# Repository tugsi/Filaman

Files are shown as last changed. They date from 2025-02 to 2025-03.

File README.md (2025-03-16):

# FilaMan - Filament Management System

[Deutsche Version](README.de.md)

FilaMan is a filament management system for 3D printing. It uses ESP32 hardware for weight measurement and NFC tag management. 
Users can manage filament spools, monitor the status of the Automatic Material System (AMS) and make settings via a web interface. 
The system integrates seamlessly with [Bambu Lab](https://bambulab.com/en-us) 3D printers and [Spoolman](https://github.com/Donkie/Spoolman) filament management.

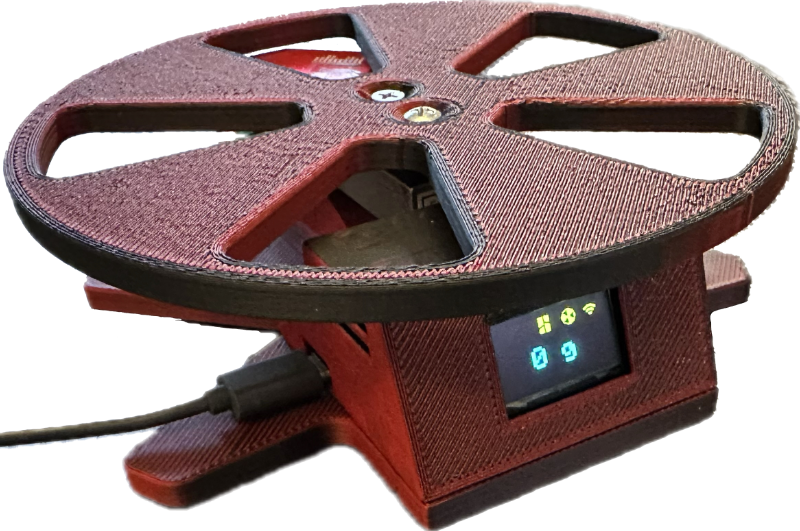
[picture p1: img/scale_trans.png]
Scale


More Images can be found in the [img Folder](/img/)  
or my website: [FilaMan Website](https://www.filaman.app)  
german explanatory video: [Youtube](https://youtu.be/uNDe2wh9SS8?si=b-jYx4I1w62zaOHU)  
Discord Server: [https://discord.gg/my7Gvaxj2v](https://discord.gg/my7Gvaxj2v)

### Now more detailed informations about the usage: [Wiki](https://github.com/ManuelW77/Filaman/wiki)

### ESP32 Hardware Features
- **Weight Measurement:** Using a load cell with HX711 amplifier for precise weight tracking.
- **NFC Tag Reading/Writing:** PN532 module for reading and writing filament data to NFC tags.
- **OLED Display:** Shows current weight, connection status (WiFi, Bambu Lab, Spoolman).
- **WiFi Connectivity:** WiFiManager for easy network configuration.
- **MQTT Integration:** Connects to Bambu Lab printer for AMS control.
- **NFC-Tag NTAG213 NTAG215:** Use NTAG213 (Capacity of 144 bytes), better NTAG215 (Capacity of 540 bytes) because of enaught space on the Tag.

### Web Interface Features
- **Real-time Updates:** WebSocket connection for live data updates.
- **NFC Tag Management:** 
	- Write filament data to NFC tags.
	- so you can use it with automatic Spool detection in AMS
- **Bambulab AMS Integration:** 
  - Display current AMS tray contents.
  - Assign filaments to AMS slots.
  - Support for external spool holder.
- **Spoolman Integration:**
  - List available filament spools.
  - Filter and select filaments.
  - Update spool weights automatically.
  - Track NFC tag assignments.
  - Supports Spoolman Octoprint Plugin.

### If you want to support my work, i would be happy to get a coffe
<a href="https://www.buymeacoffee.com/manuelw" target="_blank">Buy Me A Coffee</a>

## Detailed Functionality

### ESP32 Functionality
- **Control and Monitor Print Jobs:** The ESP32 communicates with the Bambu Lab printer to control and monitor print jobs.
- **Printer Communication:** Uses MQTT for real-time communication with the printer.
- **User Interactions:** The OLED display provides immediate feedback on the system status, including weight measurements and connection status.

### Web Interface Functionality
- **User Interactions:** The web interface allows users to interact with the system, select filaments, write NFC tags, and monitor AMS status.
- **UI Elements:** Includes dropdowns for selecting manufacturers and filaments, buttons for writing NFC tags, and real-time status indicators.

## Hardware Requirements

### Components
- **ESP32 Development Board:** Any ESP32 variant.
[Amazon Link](https://amzn.eu/d/aXThslf)
- **HX711 5kg Load Cell Amplifier:** For weight measurement.
[Amazon Link](https://amzn.eu/d/06A0DLb)
- **OLED 0.96 Zoll I2C white/yellow Display:** 128x64 SSD1306.
[Amazon Link](https://amzn.eu/d/0AuBp2c)
- **PN532 NFC NXP RFID-Modul V3:** For NFC tag operations.
[Amazon Link](https://amzn.eu/d/jfIuQXb)
- **NFC Tags NTAG213 NTAG215:** RFID Tag
[Amazon Link](https://amzn.eu/d/9Z6mXc1)

### Pin Configuration
| Component | ESP32 Pin |
|---|---|
| HX711 DOUT | 16 |
| HX711 SCK | 17 |
| OLED SDA | 21 |
| OLED SCL | 22 |
| PN532 IRQ | 32 |
| PN532 RESET | 33 |
| PN532 SDA | 21 |
| PN532 SCL | 22 |

**Make sure that the DIP switches on the PN532 are set to I2C**

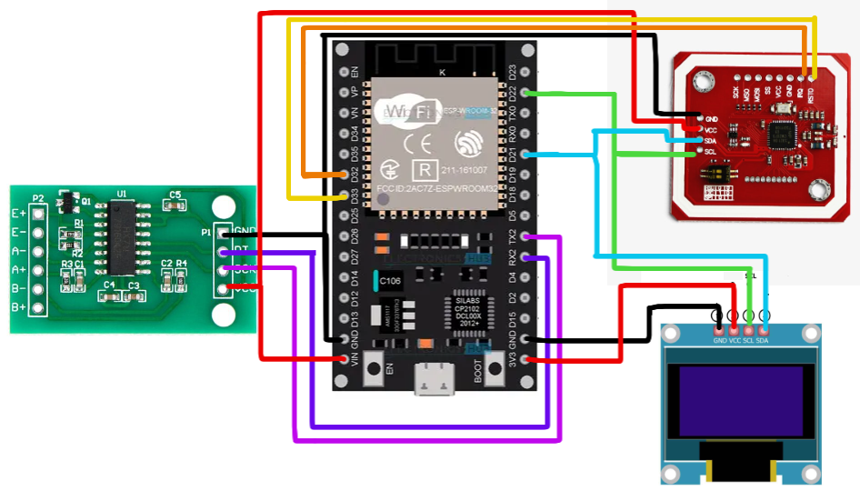
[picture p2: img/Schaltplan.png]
Wiring


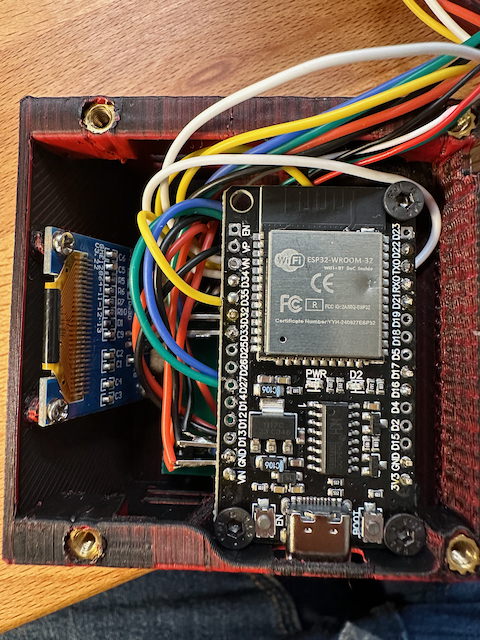
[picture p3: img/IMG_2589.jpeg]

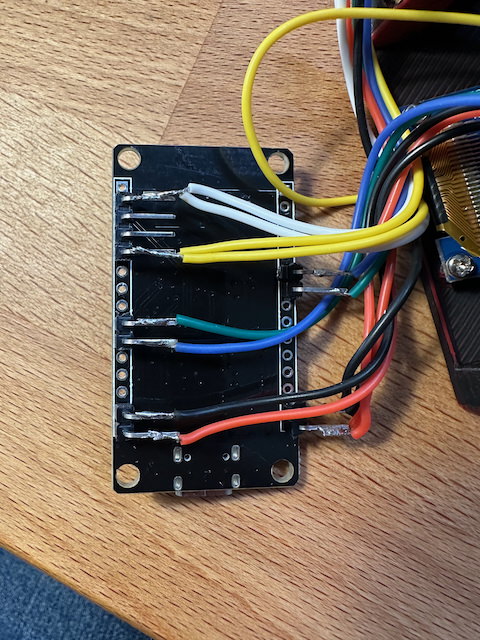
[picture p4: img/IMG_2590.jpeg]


## Software Dependencies

### ESP32 Libraries
- `WiFiManager`: Network configuration
- `ESPAsyncWebServer`: Web server functionality
- `ArduinoJson`: JSON parsing and creation
- `PubSubClient`: MQTT communication
- `Adafruit_PN532`: NFC functionality
- `Adafruit_SSD1306`: OLED display control
- `HX711`: Load cell communication

### Installation

## Prerequisites
- **Software:**
  - [PlatformIO](https://platformio.org/) in VS Code
  - [Spoolman](https://github.com/Donkie/Spoolman) instance
- **Hardware:**
  - ESP32 Development Board
  - HX711 Load Cell Amplifier
  - Load Cell (weight sensor)
  - OLED Display (128x64 SSD1306)
  - PN532 NFC Module
  - Connecting wires

## Important Note
You have to activate Spoolman in debug mode, because you are not able to set CORS Domains in Spoolman yet.

```
# Enable debug mode
# If enabled, the client will accept requests from any host
# This can be useful when developing, but is also a security risk
# Default: FALSE
#SPOOLMAN_DEBUG_MODE=TRUE
```

## Step-by-Step Installation
### Easy Installation (Google Chrome or Microsoft Edge)
1. **Go to [FilaMan Installer](https://www.filaman.app/installer.html)**

2. **Plug you device in and push Connect button**

3. **Select your Device Port and push Intall**

4. **Initial Setup:**
    - Connect to the "FilaMan" WiFi access point.
    - Configure WiFi settings through the captive portal.
    - Access the web interface at `http://filaman.local` or the IP address.

### Compile by yourself
1. **Clone the Repository:**
    ```bash
    git clone https://github.com/ManuelW77/Filaman.git
    cd FilaMan
    ```
2. **Install Dependencies:**
    ```bash
    pio lib install
    ```
3. **Flash the ESP32:**
    ```bash
    pio run --target upload
    ```
4. **Initial Setup:**
    - Connect to the "FilaMan" WiFi access point.
    - Configure WiFi settings through the captive portal.
    - Access the web interface at `http://filaman.local` or the IP address.

## Documentation

### Relevant Links
- [PlatformIO Documentation](https://docs.platformio.org/)
- [Spoolman Documentation](https://github.com/Donkie/Spoolman)
- [Bambu Lab Printer Documentation](https://www.bambulab.com/)

### Tutorials and Examples
- [PlatformIO Getting Started](https://docs.platformio.org/en/latest/tutorials/espressif32/arduino_debugging_unit_testing.html)
- [ESP32 Web Server Tutorial](https://randomnerdtutorials.com/esp32-web-server-arduino-ide/)

## License

This project is licensed under the MIT License. See the [LICENSE](LICENSE) file for details.

## Materials

### Useful Resources
- [ESP32 Official Documentation](https://docs.espressif.com/projects/esp-idf/en/latest/esp32/)
- [Arduino Libraries](https://www.arduino.cc/en/Reference/Libraries)
- [NFC Tag Information](https://learn.adafruit.com/adafruit-pn532-rfid-nfc/overview)

### Community and Support
- [PlatformIO Community](https://community.platformio.org/)
- [Arduino Forum](https://forum.arduino.cc/)
- [ESP32 Forum](https://www.esp32.com/)

## Availability

The code can be tested and the application can be downloaded from the [GitHub repository](https://github.com/ManuelW77/Filaman).

### If you want to support my work, i would be happy to get a coffe
<a href="https://www.buymeacoffee.com/manuelw" target="_blank">Buy Me A Coffee</a>

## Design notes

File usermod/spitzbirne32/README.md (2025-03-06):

## Modifications

To reduce costs, components were sourced from AliExpress instead of Amazon. However, differences in dimensions and mounting hole spacing necessitated adjustments to the 3D-printed parts. Additionally M3 heat inserts were used to limit M4 screws to a minimum.
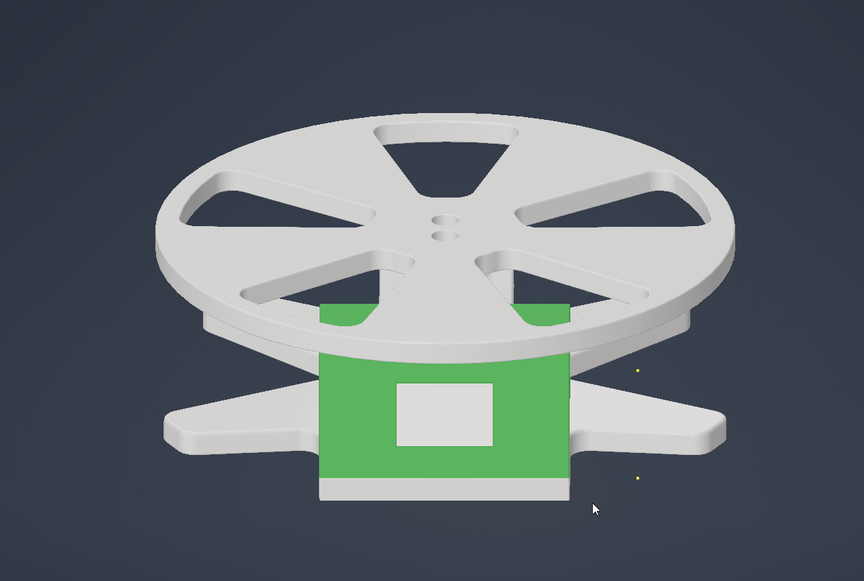
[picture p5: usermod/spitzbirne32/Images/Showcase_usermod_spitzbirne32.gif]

---

List of parts that were used:
- Display: https://aliexpress.com/item/1005007389730469.html
- Scale(5KG with HX711): https://aliexpress.com/item/1005006827930173.html
- NFC Reader: https://aliexpress.com/item/1005005973913526.html
- NFC Chips: https://aliexpress.com/item/1005006332360160.html
- [VORON](https://vorondesign.com/) Heat Inserts M3 OD5mm L4mm: https://aliexpress.com/item/1005003582355741.html  - make sure to select the correct size

---

- **Parts are designed to be printed in ABS/ASA.** Shrinking compensation not needed.

- **Display and Scale Adjustments:** The AliExpress-sourced display and scale had different dimensions and hole spacings compared to the Amazon versions. The 3D models were modified to accommodate these differences, ensuring proper fit and functionality.
   -  measurement of my Display & Scale to check if your parts will fit can be found in the images folder

- **Screw Size and Heat Inserts:** All holes originally designed for M4 screws were resized to fit M3 screws. Standard VORON heat inserts were incorporated to provide durable threading. This change standardizes the hardware and simplifies assembly.

- **Display Mounting:** The display is now mounted using M3 screws with VORON heat inserts. The display's mounting holes need to be drilled to 3mm to accommodate the M3 screws.

- **Scale Top Surface:** The top surface of the scale was modified to allow M3 socket head cap screws to sit flush with the 3D-printed part. This design ensures that the filament spool rests flat without interference.

- **NFC Reader Mounting:** The NFC reader is also secured using M3 screws and VORON heat inserts, maintaining consistency across all components.

- **Scale Base Mounting:** The only M4 screws required are for attaching the metal part of the scale to its base.

## Benefits of Modifications

- **Cost Reduction:** Sourcing components from AliExpress offers a more affordable alternative to Amazon, making the project more accessible.

- **Standardized Hardware:** Using M3 screws and [VORON](https://vorondesign.com/) heat inserts throughout the assembly simplifies the build process and reduces the variety of required hardware.

- **Enhanced Compatibility:** Adjustments to the 3D models ensure compatibility with readily available components, accommodating variations in part dimensions.

## Assembly Instructions

1. **Component Preparation:**
   - Carefully drill the display's mounting holes to 3mm to fit M3 screws.

2. **Heat Insert Installation:**
   - install VORON M3 heat inserts into the designated holes in the 3D-printed housing/case for the ESP32 and Scale top &#8594; [heat insert location pictures](./Images/README.md)

3. **Component Mounting:**
   - Attach the display, scale, and NFC reader to their respective mounts using M3 screws.
   - Secure the metal part of the scale to its base using M4 screws.

4. **Final Assembly:**
   - Assemble all components according to the original FilaMan instructions, ensuring that all modified parts fit correctly and function as intended.

For detailed assembly guides and additional resources, refer to the [original FilaMan documentation](https://github.com/ManuelW77/Filaman).

## Conclusion

These modifications to the FilaMan project provide a cost-effective and standardized approach to building a filament management system. By sourcing components from AliExpress and adjusting the 3D models accordingly, users can achieve the same functionality at a reduced cost, with the added benefit of using uniform hardware throughout the assembly.

## Changelog

### Version 1.0 - 2025-03-04
- Initial release of modifications for AliExpress-sourced components.
- Adjusted 3D models to fit different display and scale dimensions.
- Replaced M4 screws with M3 screws and integrated VORON heat inserts.
- Modified display mounting, requiring drilling to 3mm for M3 screws.
- Adjusted scale top surface for flush screw placement.
- Standardized NFC reader mounting with M3 screws and VORON heat inserts.
- Retained M4 screws only for metal scale attachment.

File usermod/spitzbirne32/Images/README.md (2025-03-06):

## **Heat insert location**

Housing: 
- every hole is made to fit a heat insert
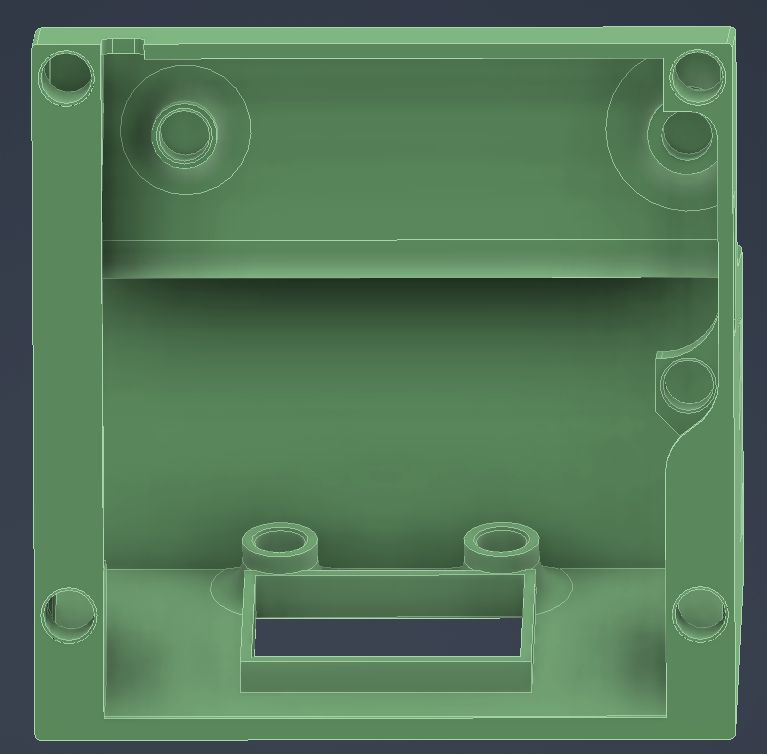
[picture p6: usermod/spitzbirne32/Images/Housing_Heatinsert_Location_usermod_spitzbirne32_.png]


---
Scale top: 
- two heat inserts for the NFC Reader
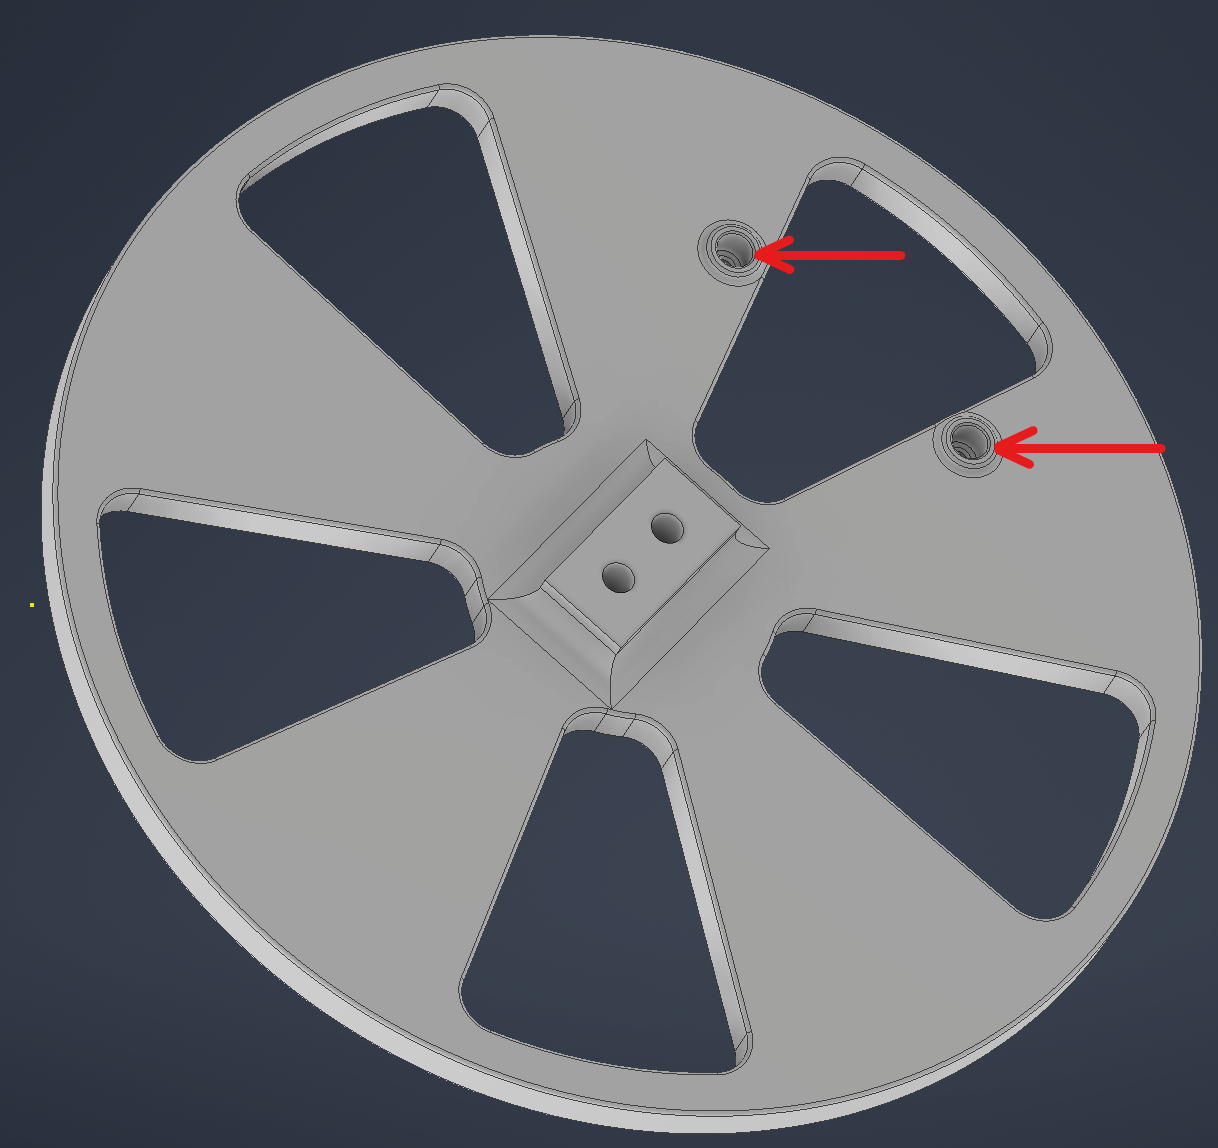
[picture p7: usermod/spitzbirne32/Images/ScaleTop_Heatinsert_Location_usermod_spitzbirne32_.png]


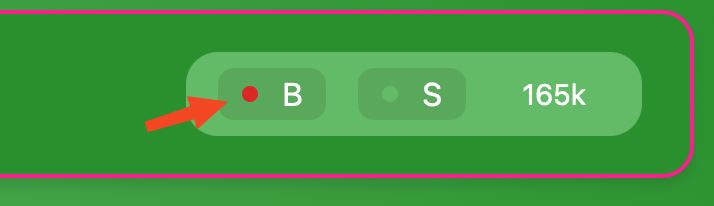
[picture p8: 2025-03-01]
img/7-enable.png

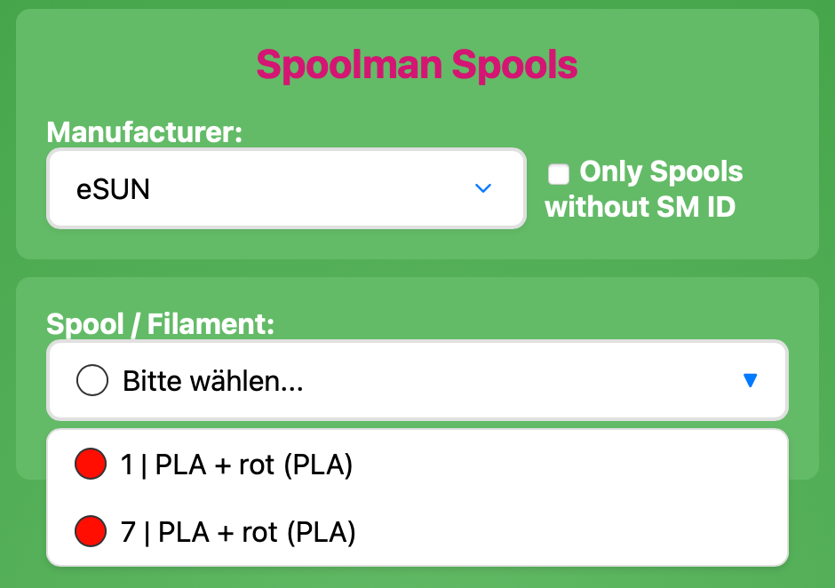
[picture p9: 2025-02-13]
img/web_spoolman.png

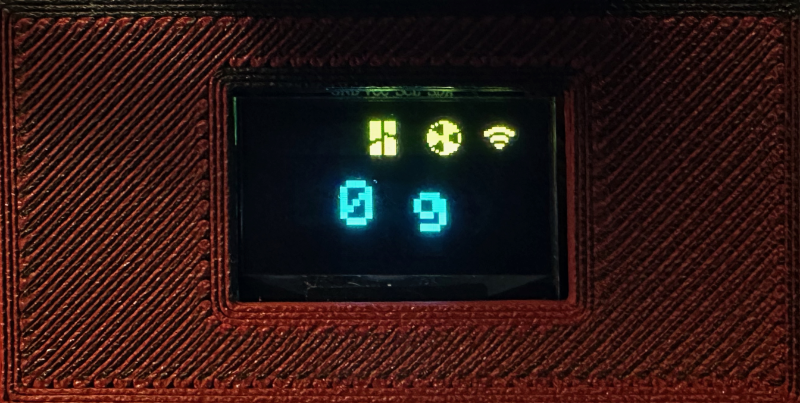
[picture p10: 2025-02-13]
img/display_1.png

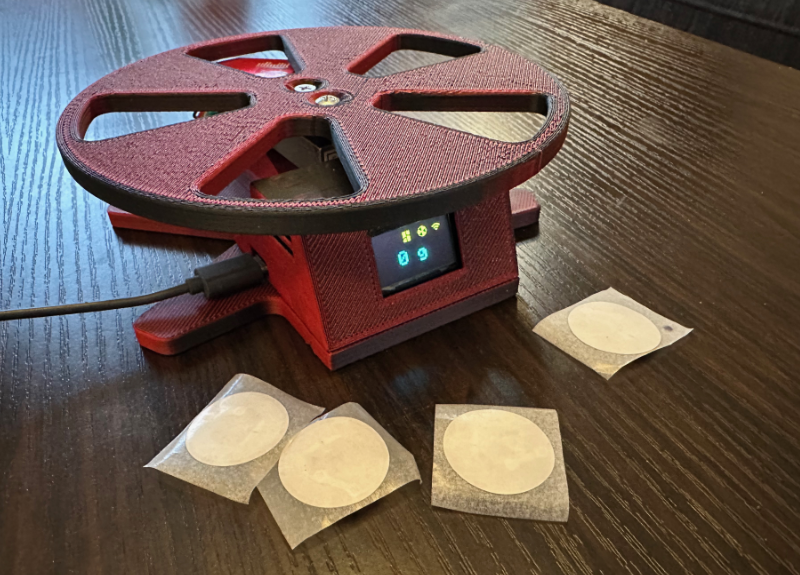
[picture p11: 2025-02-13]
img/scale_1.png

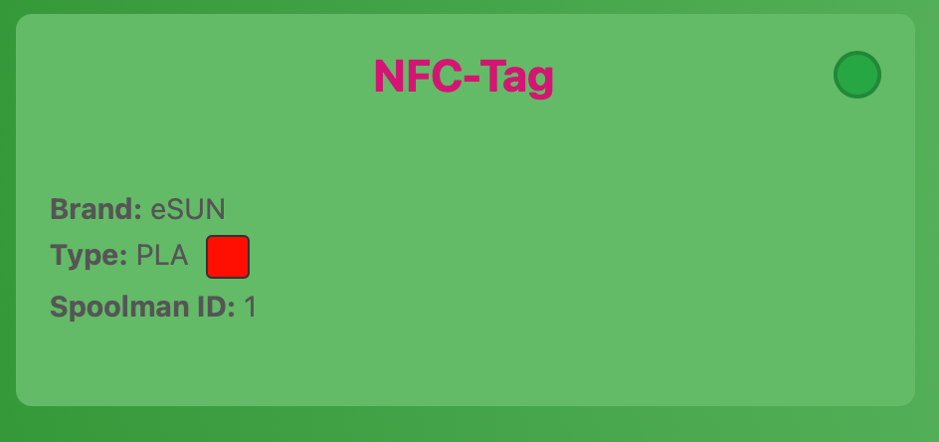
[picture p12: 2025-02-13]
img/web_nfc.png

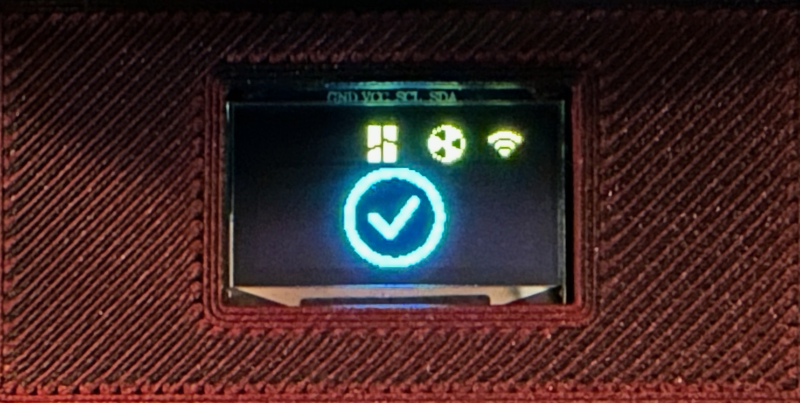
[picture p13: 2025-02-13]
img/display_4.png

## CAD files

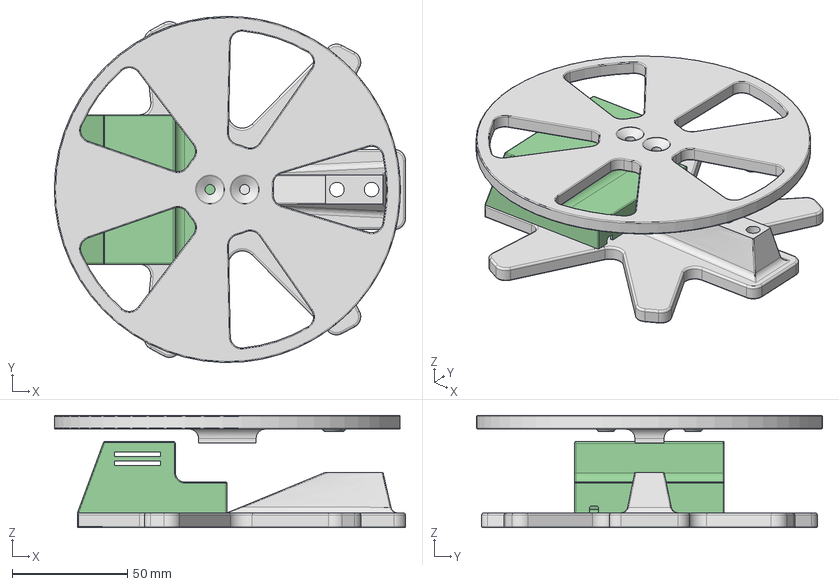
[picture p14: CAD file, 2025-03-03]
_3D Print Files/FilaMan-Waage.step
152.3 x 150.0 x 48.7 mm
Boden
Spulenablage
Deckel

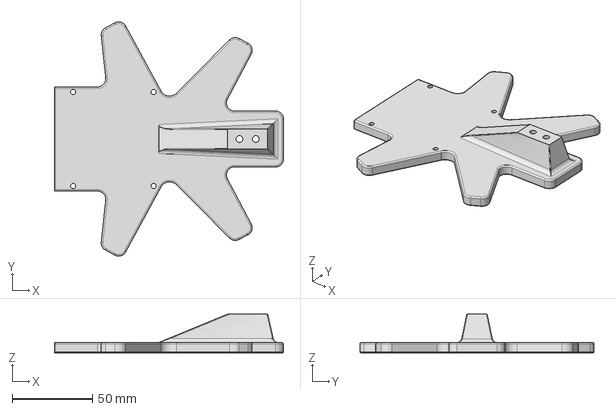
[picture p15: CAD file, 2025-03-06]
usermod/spitzbirne32/CAD/Base_usermod_spitzbirne32.stp
142.3 x 145.6 x 24.0 mm

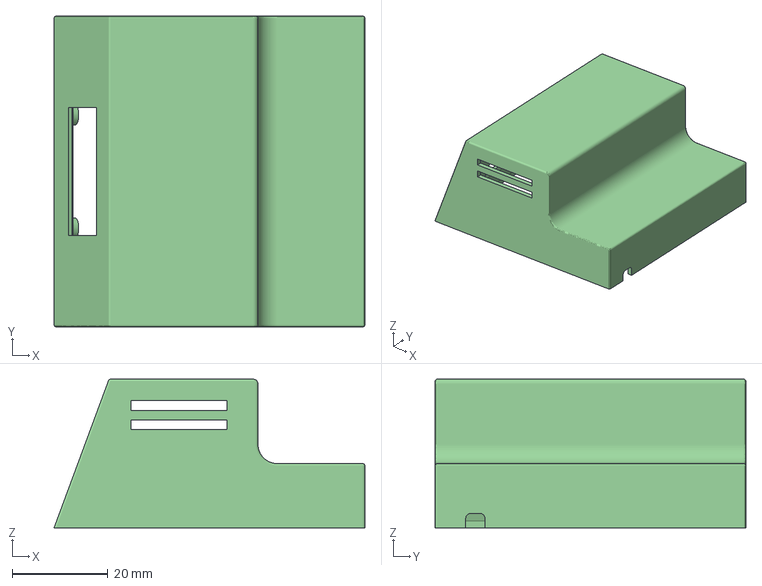
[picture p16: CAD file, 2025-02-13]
_3D Print Files/Housing.3mf
64.8 x 64.8 x 31.0 mm

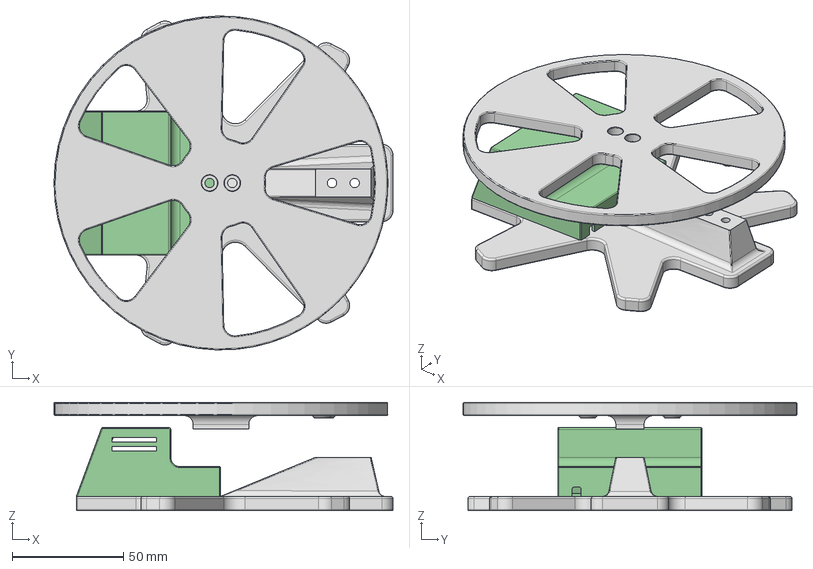
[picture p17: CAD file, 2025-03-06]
usermod/spitzbirne32/CAD/FilaMan-Scale_usermod_spitzbirne32.stp
152.3 x 150.0 x 48.7 mm
Boden
Spulenablage
Deckel

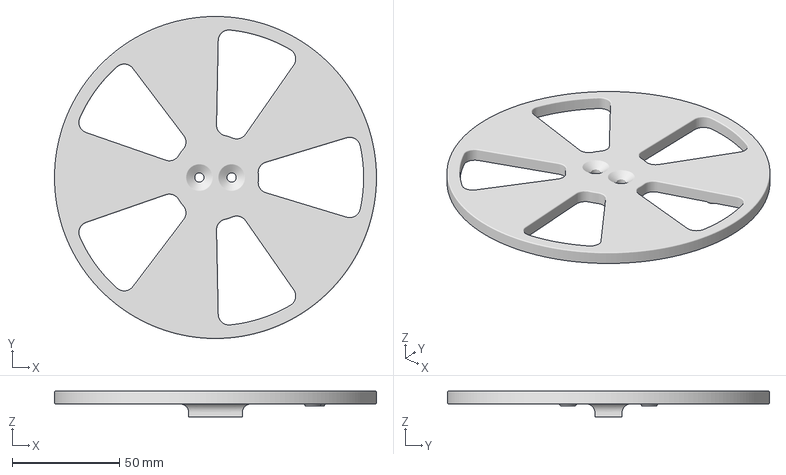
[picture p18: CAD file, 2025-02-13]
_3D Print Files/Table.3mf
150.0 x 150.0 x 12.0 mm

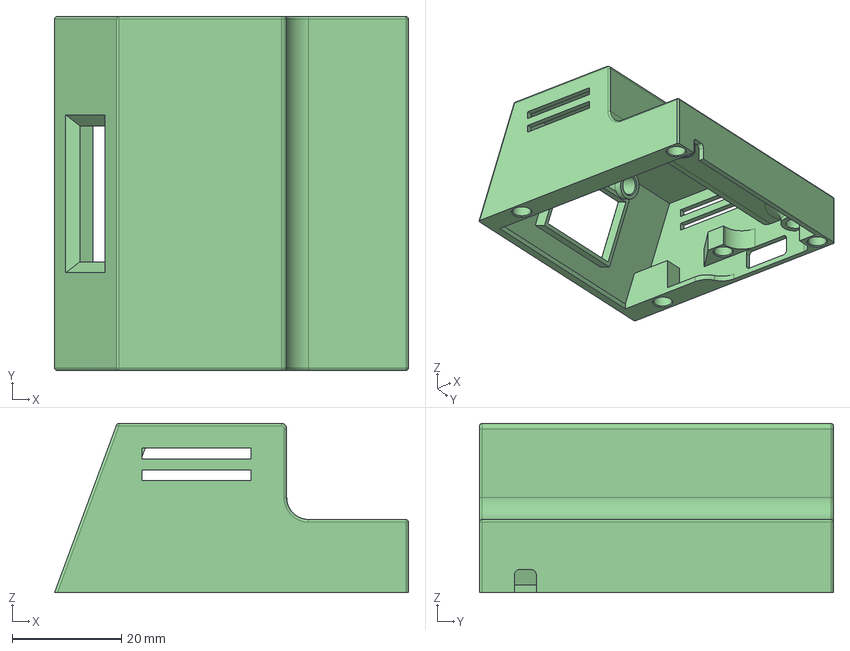
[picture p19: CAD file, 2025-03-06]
usermod/spitzbirne32/CAD/Housing_usermod_spitzbirne32.stp
64.8 x 64.8 x 31.0 mm

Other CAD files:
usermod/spitzbirne32/CAD/ScaleTop_usermod_spitzbirne32.stp
_3D Print Files/Bottom.3mf
usermod/spitzbirne32/STL/Base_usermod_spitzbirne32.stl
usermod/spitzbirne32/STL/Housing_usermod_spitzbirne32.stl
usermod/spitzbirne32/STL/ScaleTop_usermod_spitzbirne32.stl

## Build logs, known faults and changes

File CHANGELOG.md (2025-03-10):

# Changelog

## [1.4.1] - 2025-03-10
### Added
- added new .step, now with correct individual parts
- added changelog
- Add files via upload
- added .stp files of modifications
- added merged picture
- added pictures of components bought from AliE
- Add files via upload
- added pictures for heat insert location
- added pictures showing heat insert location
- remove unnecessary delay in MQTT setup and add delay before restart
- add new 3D print file for Filaman scale
- added Discord Server

### Changed
- update platformio.ini for version v1.4.1
- refactor length calculation to convert total length to meters before formatting
- Merge pull request #16 from spitzbirne32/main
- improved housing to show display better
- removed CAD, as they were all duplicates
- typo in AliE link
- Delete usermod/spitzbirne32/STL/README.md
- Update README.md
- moved pictures of parts into dedicated folders
- Update README.md
- Update README.md
- Update README.md
- Delete usermod/spitzbirne32/STL/ScaleTop_Heatinsert_Location_usermod_spitzbirne32_.png
- Delete usermod/spitzbirne32/STL/Housing_Heatinsert_Location_usermod_spitzbirne32_.png
- created folders
- Update README.md
- Update README.md
- Create README.md
- Update README.md
- Update README.md
- Create README.md
- Merge pull request #15 from ManuelW77/main
- Merge pull request #14 from janecker/scale-calibration-rework
- Reworks the scale calibration handling
- remove redundant scale calibration checks and enhance task management
- enhance AMS data handling and streamline spool auto-setting logic
- adjust stack size and improve scale calibration logic
- update labels and input types for better clarity and functionality
- update documentation for clarity and accuracy

### Fixed
- correct typo in console log for total length

## [1.4.0] - 2025-03-01
### Added
- add support for Spoolman Octoprint Plugin in README files
- add OctoPrint integration with configurable fields and update functionality
- add version comparison function and check for outdated versions before updates
- remove unused version and protocol fields from JSON output; add error message for insufficient memory

### Changed
- update NFC tag references to include NTAG213 and clarify storage capacity
- bump version to 1.4.0
- remove unused version and protocol fields from NFC data packet
- sort vendors alphabetically in the dropdown list
- Merge pull request #10 from janecker/nfc-improvements
- Improves NFC Tag handling

## [1.3.99] - 2025-02-28
### Changed
- update platformio.ini for version v1.3.99
- update workflows to build firmware with LittleFS instead of SPIFFS

## [1.3.98] - 2025-02-28
### Changed
- update platformio.ini for version v1.3.98
- migrate from SPIFFS to LittleFS for file handling
- remove unused VSCode settings file
- remove commented-out spoolman and filaman data from api.cpp

## [1.3.97] - 2025-02-28
### Added
- füge Bestätigungsmeldung für Spool-Einstellung hinzu
- verbessere WLAN-Konfiguration und füge mDNS-Unterstützung hinzu
- aktualisiere OLED-Anzeige mit Versionsnummer und verbessere Textausrichtung
- füge regelmäßige WLAN-Verbindungsüberprüfung hinzu
- aktualisiere Schaltplan-Bild
- zeige Versionsnummer im OLED-Display an

### Changed
- update platformio.ini for version v1.3.97
- entferne text-shadow von deaktivierten Schaltflächen
- füge Link zum Wiki für detaillierte Informationen über die Nutzung hinzu

### Fixed
- Speichernutzung optimiert
- behebe doppelte http.end() Aufrufe in checkSpoolmanExtraFields
- optimiere Verzögerungen und Stackgrößen in NFC-Task-Funktionen
- entferne ungenutzte Bibliotheken und Debug-Ausgaben aus main.cpp

## [1.3.96] - 2025-02-25
### Added
- füge Unterstützung für Spoolman-Einstellungen hinzu und aktualisiere die Benutzeroberfläche
- entferne die sendAmsData-Funktion aus der API-Schnittstelle
- erweitere Bambu-Credentials um AutoSend-Zeit und aktualisiere die Benutzeroberfläche
- erweitere Bambu-Credentials mit AutoSend-Wartezeit und aktualisiere die Benutzeroberfläche
- add espRestart function and replace delay with vTaskDelay for OTA update process
- implement OTA update functionality with backup and restore for configurations
- add own_filaments.json and integrate custom filament loading in bambu.cpp

### Changed
- update platformio.ini for version v1.3.96

### Fixed
- aktualisiere Bedingungen für die AMS-Datenaktualisierung und entferne unnötige Aufrufe
- aktualisiere Bedingung für den Fortschritt der OTA-Update-Nachricht
- update auto set logic to check RFID tag before setting Bambu spool

## [1.3.95] - 2025-02-24
### Changed
- update webpages for version v1.3.95

### Fixed
- bind autoSendToBambu variable to checkbox in spoolman.html

## [1.3.94] - 2025-02-24
### Changed
- update webpages for version v1.3.94

### Fixed
- correct payload type check in NFC write event handling

## [1.3.93] - 2025-02-24
### Added
- implement auto send feature for Bambu spool management and update related configurations
- add debug mode instructions for Spoolman in README
- add wiring diagrams to README for PN532 I2C setup

### Changed
- update webpages for version v1.3.93
- simplify filament names in JSON configuration
- update findFilamentIdx to return structured result and improve type searching logic
- update README to reflect PN532 I2C configuration and remove SPI pin details

### Fixed
- remove debug output from splitTextIntoLines and update weight display logic in scanRfidTask
- enhance weight display logic for negative values
- remove unnecessary CPU frequency configuration from setup function

## [1.3.92] - 2025-02-24
### Changed
- update webpages for version v1.3.92
- remove commented-out code in setBambuSpool function
- update installation instructions and formatting in README files

### Fixed
- configure CPU frequency settings in setup function only for testing
- update comment to clarify NVS reading process
- adjust weight display logic to handle cases for weight less than 2
- update weight display logic to handle negative and specific weight cases

## [1.3.91] - 2025-02-23
### Added
- update GitHub Actions workflow for FTP firmware upload with improved credential checks

### Changed
- update webpages for version v1.3.91

## [1.3.90] - 2025-02-23
### Added
- update index.html for improved content structure and additional links
- improve UI for Spoolman and Bambu Lab printer credentials, enhancing layout and styling
- update README files with HSPI default PINs and add ESP32 pin diagram
- implement scale calibration checks and update start_scale function to return calibration status
- add FTP upload functionality to GitHub release workflow and update installation instructions in README

### Changed
- update webpages for version v1.3.90

### Fixed
- remove debug secrets check from Gitea release workflow

## [1.3.89] - 2025-02-23
### Changed
- update webpages for version v1.3.89

### Fixed
- update Gitea release workflow to use vars for FTP credentials

## [1.3.88] - 2025-02-23
### Changed
- update webpages for version v1.3.88

### Fixed
- update Gitea release workflow to use secrets for FTP credentials

## [1.3.87] - 2025-02-23
### Changed
- update webpages for version v1.3.87

### Fixed
- enhance FTP upload workflow with credential checks and version output

## [1.3.86] - 2025-02-23
### Changed
- update webpages for version v1.3.86

### Fixed
- streamline FTP credentials usage in Gitea release workflow

## [1.3.85] - 2025-02-23
### Added
- add FTP_USER variable for Gitea release workflow

### Changed
- update webpages for version v1.3.85

## [1.3.84] - 2025-02-23
### Added
- add FTP_HOST variable for firmware upload in Gitea release workflow

### Changed
- update webpages for version v1.3.84

## [1.3.83] - 2025-02-23
### Changed
- update webpages for version v1.3.83

### Fixed
- correct variable interpolation for FTP credentials in Gitea release workflow

## [1.3.82] - 2025-02-23
### Added
- update Gitea release workflow to use variable interpolation for FTP credentials

### Changed
- update webpages for version v1.3.82

## [1.3.81] - 2025-02-23
### Added
- update Gitea release workflow to use environment variables for FTP credentials and version

### Changed
- update webpages for version v1.3.81

## [1.3.80] - 2025-02-23
### Added
- add FTP_USER and FTP_PASSWORD secrets for firmware upload in Gitea release workflow

### Changed
- update webpages for version v1.3.80

## [1.3.79] - 2025-02-23
### Added
- add FTP_USER input for firmware upload in Gitea release workflow

### Changed
- update webpages for version v1.3.79

## [1.3.78] - 2025-02-23
### Changed
- update webpages for version v1.3.78

### Fixed
- change FTP protocol from FTPS to FTP for file upload in workflow

## [1.3.77] - 2025-02-23
### Changed
- update webpages for version v1.3.77

### Fixed
- replace ncftp with lftp for secure firmware upload

## [1.3.76] - 2025-02-23
### Changed
- update webpages for version v1.3.76

### Fixed
- replace FTP action with curl for secure firmware upload and install ncftp

## [1.3.75] - 2025-02-23
### Changed
- update webpages for version v1.3.75

### Fixed
- update FTP user and enhance SSL options in gitea-release workflow

## [1.3.74] - 2025-02-23
### Changed
- update webpages for version v1.3.74

### Fixed
- update password syntax in gitea-release workflow

## [1.3.73] - 2025-02-23
### Changed
- update webpages for version v1.3.73
- update version to 1.3.72 in platformio.ini

## [1.3.72] - 2025-02-23
### Changed
- update webpages for version v1.3.72

### Fixed
- update FTP options for Gitea release workflow

## [1.3.71] - 2025-02-23
### Added
- add FTP upload step for firmware in Gitea release workflow

### Changed
- update webpages for version v1.3.71

## [1.3.70] - 2025-02-23
### Changed
- update webpages for version v1.3.70

## [1.3.69] - 2025-02-23
### Changed
- update webpages for version v1.3.69

### Fixed
- update release note generation to use the second latest tag

## [1.3.68] - 2025-02-23
### Changed
- update webpages for version v1.3.68

### Fixed
- update release note generation to include commit hash and author
- remove commented test line from platformio.ini

## [1.3.67] - 2025-02-23
### Changed
- update webpages for version v1.3.67
- ci: update release note generation to use the latest tag

## [1.3.66] - 2025-02-23
### Changed
- update webpages for version v1.3.66
- ci: remove redundant git fetch for tags in release note generation

## [1.3.65] - 2025-02-22
### Changed
- update webpages for version v1.3.65
- ci: improve release note generation by fetching tags and sorting unique commits

## [1.3.64] - 2025-02-22
### Changed
- update webpages for version v1.3.64
- remove unnecessary closing tags from header.html

## [1.3.63] - 2025-02-22
### Added
- update update-form background and add glass border effect

### Changed
- update webpages for version v1.3.63
- update release note generation for initial release handling

## [1.3.62] - 2025-02-22
### Changed
- update webpages for version v1.3.62
- update background colors and improve layout for update sections

## [1.3.61] - 2025-02-22
### Added
- update release notes generation to use previous tag for changes

### Changed
- update webpages for version v1.3.61

## [1.3.60] - 2025-02-22
### Added
- remove automatic git push from changelog update script
- implement release notes generation with categorized changes since last tag

### Changed
- update webpages for version v1.3.60

## [1.3.59] - 2025-02-22
### Added
- implement enhanced update progress handling and WebSocket notifications
- improve update progress reporting and enhance WebSocket notifications
- enhance update progress handling and add WebSocket closure notification
- implement WebSocket for update progress and enhance update response handling

### Changed
- update webpages for version v1.3.59

## [1.3.58] - 2025-02-22
### Added
- implement backup and restore functionality for Bambu credentials and Spoolman URL

### Changed
- update webpages for version v1.3.58
- update upgrade page message and improve progress display logic

## [1.3.57] - 2025-02-22
### Changed
- update webpages for version v1.3.57
- update header title to 'Filament Management Tool' in multiple HTML files

## [1.3.56] - 2025-02-22
### Changed
- update webpages for version v1.3.56
- update header title and improve SPIFFS update error handling
- clarify comments in Gitea and GitHub release workflows

## [1.3.55] - 2025-02-22
### Changed
- update webpages for version v1.3.55
- update component descriptions in README files

## [1.3.54] - 2025-02-22
### Changed
- update webpages for version v1.3.54
- workflow: update SPIFFS binary creation to exclude header

## [1.3.53] - 2025-02-22
### Changed
- version: update to version 1.3.53
- update changelog for version 1.3.51
- update changelog for version 1.3.51
- workflow: update SPIFFS binary magic byte and revert version to 1.3.51

## [1.3.52] - 2025-02-22
### Changed
- update webpages for version v1.3.52
- workflow: update SPIFFS binary creation to use correct chip revision (0xEB for Rev 3)

## [1.3.51] - 2025-02-22
### Changed
- update changelog for version 1.3.51
- workflow: update SPIFFS binary magic byte and revert version to 1.3.51

## [1.3.50] - 2025-02-22
### Changed
- update webpages for version v1.3.50

## [1.3.49] - 2025-02-22
### Changed
- update webpages for version v1.3.49
- workflow: update SPIFFS binary header to use correct chip revision

## [1.3.48] - 2025-02-22
### Changed
- update webpages for version v1.3.48
- workflow: update SPIFFS binary header for firmware release

## [1.3.47] - 2025-02-22
### Changed
- update webpages for version v1.3.47
- workflow: optimize firmware and SPIFFS update process, improve progress handling and logging

## [1.3.46] - 2025-02-22
### Changed
- update webpages for version v1.3.46

## [1.3.45] - 2025-02-22
### Changed
- update webpages for version v1.3.45
- workflow: update SPIFFS binary creation to include minimal header and adjust update validation logic

## [1.3.44] - 2025-02-22
### Changed
- update webpages for version v1.3.44
- update header title to 'Hollo Lollo Trollo'
- update header title to 'Filament Management Tool' and improve update response messages

## [1.3.43] - 2025-02-22
### Changed
- update webpages for version v1.3.43
- update header title to 'Hollo Lollo Trollo'

## [1.3.42] - 2025-02-22
### Changed
- update webpages for version v1.3.42

### Fixed
- correct path for SPIFFS binary creation in Gitea release workflow

## [1.3.41] - 2025-02-22
### Changed
- update webpages for version v1.3.41

### Fixed
- remove redundant buffer size setting in NFC initialization
- update SPIFFS binary creation and enhance NFC buffer size

## [1.3.40] - 2025-02-22
### Changed
- update webpages for version v1.3.40

### Fixed
- update SPIFFS binary header and enhance WebSocket error handling

## [1.3.39] - 2025-02-22
### Changed
- update webpages for version v1.3.39
- workflow: update SPIFFS binary creation to set chip version to max supported

## [1.3.38] - 2025-02-22
### Changed
- update webpages for version v1.3.38
- workflow: update SPIFFS binary creation with minimal ESP32 image header

## [1.3.37] - 2025-02-22
### Changed
- update webpages for version v1.3.37
- workflow: update ESP32-WROOM image header for SPIFFS binary creation

## [1.3.36] - 2025-02-22
### Changed
- update webpages for version v1.3.36
- partition: update SPIFFS binary header and offsets in workflow files

## [1.3.35] - 2025-02-22
### Changed
- update webpages for version v1.3.35
- partition: update SPIFFS binary header and offsets in workflow files

## [1.3.34] - 2025-02-22
### Changed
- update webpages for version v1.3.34
- partition: update SPIFFS binary creation and offsets in workflow files

## [1.3.33] - 2025-02-22
### Changed
- update webpages for version v1.3.33
- partition: update spiffs offset and app sizes in partition files
- partition: update spiffs offset in partition files
- partition: update app sizes and offsets in partitions.csv

## [1.3.32] - 2025-02-22
### Changed
- update webpages for version v1.3.32
- workflow: update magic byte for SPIFFS binary creation

## [1.3.31] - 2025-02-22
### Changed
- update webpages for version v1.3.31
- workflow: remove unnecessary data and SPIFFS change checks from release workflows

## [1.3.30] - 2025-02-22
### Changed
- update webpages for version v1.3.30
- workflow: update Gitea and GitHub release workflows to create SPIFFS binary with magic byte

## [1.3.29] - 2025-02-21
### Changed
- update webpages for version v1.3.29
- workflow: update Gitea release workflow to create release before file uploads

## [1.3.28] - 2025-02-21
### Changed
- update webpages for version v1.3.28
- workflow: update Gitea release workflow to use file uploads with curl

## [1.3.27] - 2025-02-21
### Added
- workflow: add GITEA_TOKEN secret for Gitea API access in release workflows

### Changed
- update webpages for version v1.3.27

## [1.3.26] - 2025-02-21
### Changed
- update webpages for version v1.3.26

### Fixed
- workflow: improve Gitea release workflow with enhanced error handling and debug outputs

## [1.3.25] - 2025-02-21
### Changed
- update webpages for version v1.3.25
- workflow: update Gitea release workflow to include RUNNER_NAME and improve error handling

## [1.3.24] - 2025-02-21
### Changed
- update webpages for version v1.3.24
- workflow: rename update files to upgrade in GitHub release workflow
- workflow: aktualisiere bestehende Einträge im Changelog für vorhandene Versionen

### Fixed
- workflow: improve Gitea release process with dynamic URL determination and debug outputs

## [1.3.23] - 2025-02-21
### Changed
- update webpages for version v1.3.23

### Fixed
- workflow: enhance Gitea release process with debug outputs and API connection checks

## [1.3.22] - 2025-02-21
### Added
- workflow: improve Gitea release process with additional environment variables and error handling

### Changed
- update webpages for version v1.3.22

## [1.3.21] - 2025-02-21
### Changed
- update webpages for version v1.3.21
- workflow: enhance Gitea release process with API integration and token management

## [1.3.20] - 2025-02-21
### Changed
- update webpages for version v1.3.20
- workflow: enable git tagging and pushing for Gitea releases

## [1.3.19] - 2025-02-21
### Changed
- update webpages for version v1.3.19
- workflow: enable git push for version tagging in Gitea release

## [1.3.18] - 2025-02-21
### Changed
- ACHTUNG: Installiere einmal das filaman_full.bin danach kannst du über die upgrade Files aktualisieren und deine Settings bleiben auch erhalten.
- ATTENTION: Install the filaman_full.bin once, then you can update via the upgrade files and your settings will also be retained.

## [1.3.18] - 2025-02-21
### Added
- add note about filaman_full.bin installation in changelog

### Changed
- update webpages for version v1.3.18
- update changelog for version 1.3.18 and enhance update script for existing entries

## [1.3.17] - 2025-02-21
### Changed
- update webpages for version v1.3.17
- ci: comment out git tag and push commands in gitea-release workflow

## [1.3.16] - 2025-02-21
### Changed
- update webpages for version v1.3.16
- ci: update filenames for firmware and website binaries in release workflows

## [1.3.15] - 2025-02-21
### Changed
- update webpages for version v1.3.15

### Fixed
- ci: fix missing 'fi' in GitHub release workflow script

## [1.3.14] - 2025-02-21
### Changed
- update webpages for version v1.3.14
- ci: update GitHub release workflow to improve file upload handling

## [1.3.13] - 2025-02-21
### Changed
- update webpages for version v1.3.13
- ci: update GitHub release workflow to use RELEASE_TOKEN for improved security

## [1.3.12] - 2025-02-21
### Changed
- update webpages for version v1.3.12
- ci: enhance GitHub release workflow with token handling and file upload improvements

## [1.3.11] - 2025-02-21
### Changed
- update webpages for version v1.3.11
- ci: refactor Gitea release workflow by simplifying input handling and removing unnecessary checks

## [1.3.10] - 2025-02-21
### Changed
- update webpages for version v1.3.10
- ci: simplify GitHub release workflow by removing provider verification step

## [1.3.9] - 2025-02-21
### Changed
- update webpages for version v1.3.9
- ci: comment out permissions for GitHub release workflow

## [1.3.8] - 2025-02-21
### Added
- add Gitea and GitHub release workflows

### Changed
- update webpages for version v1.3.8

## [1.3.7] - 2025-02-21
### Added
- add GitHub and Gitea release workflows

### Changed
- update webpages for version v1.3.7

## [1.3.6] - 2025-02-21
### Changed
- update webpages for version v1.3.6

### Fixed
- update GitHub token reference and correct file path in release workflow

## [1.3.5] - 2025-02-21
### Added
- enhance release workflow to support Gitea alongside GitHub

### Changed
- update webpages for version v1.3.5

## [1.3.4] - 2025-02-21
### Added
- add Gitea and GitHub release workflows

### Changed
- update webpages for version v1.3.4
- Merge branch 'old'

## [1.3.3] - 2025-02-21
### Changed
- update webpages for version v1.3.3

### Fixed
- correct directory path in GitHub workflows for SPIFFS binary

## [1.3.2] - 2025-02-21
### Added
- add missing conditional exit in release workflow

### Changed
- update webpages for version v1.3.2

## [1.3.1] - 2025-02-21
### Added
- enhance GitHub and Gitea release workflows with Python setup and binary preparation

### Changed
- update webpages for version v1.3.1

## [1.3.0] - 2025-02-21
### Changed
- bump version to 1.3.0 in platformio.ini

## [1.2.102] - 2025-02-21
### Changed
- update webpages for version v1.2.102

### Fixed
- adjust bootloader offset in binary merge for Gitea and GitHub workflows

## [1.2.101] - 2025-02-21
### Changed
- update webpages for version v1.2.101
- always create SPIFFS binary in release workflows
- migrate calibration value storage from EEPROM to NVS

## [1.2.100] - 2025-02-21
### Changed
- update webpages for version v1.2.100
- remove OTA handling and JSON backup/restore functions

## [1.2.99] - 2025-02-21
### Added
- add SPIFFS change detection and binary copying to release workflows
- add backup and restore functions for JSON configurations during OTA updates

### Changed
- update webpages for version v1.2.99
- update JSON field type checks from JsonObject to String for improved validation
- update JSON handling in API and Bambu modules for improved object management
- update platformio.ini dependencies and improve version handling in website.cpp
- update Cache-Control header to reflect a 1-week duration
- remove version definition from website.cpp
- optimize WiFi and WebSocket settings; enhance TCP/IP stack configuration
- update upgrade page title and heading; adjust cache control duration

## [1.2.98] - 2025-02-21
### Changed
- update webpages for version v1.2.98

## [1.2.97] - 2025-02-21
### Changed
- update webpages for version v1.2.97
- streamline Gitea and GitHub release workflows to check for data changes and update binary handling

## [1.2.96] - 2025-02-21
### Added
- add SPIFFS build step to Gitea and GitHub release workflows

### Changed
- update webpages for version v1.2.96

## [1.2.95] - 2025-02-21
### Added
- enhance update process with separate forms for firmware and webpage uploads, including validation and improved UI
- add API endpoint for version retrieval and update HTML to display dynamic version

### Changed
- update webpages for version v1.2.95
- bump version to 1.2.94 in platformio.ini

## [1.2.91] - 2025-02-20
### Added
- add file existence checks before uploading binaries in release workflows

### Changed
- update webpages for version v1.2.91

## [1.2.90] - 2025-02-20
### Changed
- update webpages for version v1.2.90
- update Gitea and GitHub release workflows to include SPIFFS directory creation and firmware copying

## [1.2.89] - 2025-02-20
### Changed
- update webpages for version v1.2.89
- enhance OTA update process with SPIFFS support and improved error handling

## [1.2.88] - 2025-02-20
### Changed
- update webpages for version v1.2.88

### Fixed
- improve OTA update handling and logging for better error reporting

## [1.2.87] - 2025-02-20
### Changed
- update webpages for version v1.2.87

### Fixed
- update firmware build process and remove unused OTA environment

## [1.2.86] - 2025-02-20
### Changed
- update webpages for version v1.2.86

### Fixed
- update SPIFFS offset and size in release workflows and partitions.csv

## [1.2.85] - 2025-02-20
### Added
- ci: streamline release workflows by removing unnecessary binary uploads and adding SPIFFS formatting

### Changed
- update webpages for version v1.2.85

## [1.2.84] - 2025-02-20
### Changed
- update webpages for version v1.2.84
- ci: update installation steps for xxd to include package list update

## [1.2.83] - 2025-02-20
### Changed
- update webpages for version v1.2.83
- replace hexdump with xxd for magic byte verification in release workflows

## [1.2.82] - 2025-02-20
### Changed
- update webpages for version v1.2.82
- enhance Gitea and GitHub release workflows to include magic byte handling and improve binary verification

## [1.2.81] - 2025-02-20
### Changed
- update webpages for version v1.2.81
- update Gitea and GitHub release workflows to use esp32dev_ota for building and uploading firmware and SPIFFS binaries

## [1.2.80] - 2025-02-20
### Added
- update Gitea and GitHub release workflows to include new firmware and SPIFFS binaries; fix version display in HTML files to v1.2.78

### Changed
- update webpages for version v1.2.80
- bump version to 1.2.79 in platformio.ini

## [1.2.79] - 2025-02-20
### Changed
- update webpages for version v1.2.79
- simplify Gitea release workflow by using esptool for binary creation

## [1.2.78] - 2025-02-20
### Changed
- update webpages for version v1.2.78
- streamline Gitea release workflow and update version to 1.2.77

### Fixed
- update Gitea and GitHub release workflows to improve binary preparation and verification fix: correct version number in HTML files and platformio.ini to v1.2.76 enhance: streamline OTA update handling by removing unnecessary magic byte checks

## [1.2.77] - 2025-02-20
### Changed
- optimize Gitea release workflow by simplifying build steps and improving file handling
- update webpages for version v1.2.77

## [1.2.76] - 2025-02-20
### Added
- enhance OTA update process with improved file verification and new OTA data initialization

### Changed
- update webpages for version v1.2.76
- streamline Gitea release workflow and remove obsolete OTA data initialization script

## [1.2.75] - 2025-02-20
### Changed
- update webpages for version v1.2.75
- simplify OTA update handling by removing unnecessary variables and improving error reporting

## [1.2.74] - 2025-02-20
### Changed
- update webpages for version v1.2.74
- enhance OTA update process with improved handling of full image updates and SPIFFS data

## [1.2.73] - 2025-02-20
### Changed
- update webpages for version v1.2.73
- improve OTA update process with enhanced size checks and progress logging

### Fixed
- enhance OTA update process with improved size checks and debugging output

## [1.2.72] - 2025-02-20
### Changed
- update webpages for version v1.2.72
- simplify OTA update process by removing unnecessary buffer and adjusting offsets

## [1.2.71] - 2025-02-20
### Added
- update version number to v1.2.65 in HTML files and platformio.ini; add script to create full binary

### Changed
- update webpages for version v1.2.71

## [1.2.70] - 2025-02-20
### Added
- add logging to stopAllTasks for better debugging

### Changed
- update webpages for version v1.2.70

## [1.2.69] - 2025-02-20
### Changed
- update webpages for version v1.2.69

## [1.2.68] - 2025-02-20
### Added
- add task handles for BambuMqttTask and ScaleTask; rename stopTasks to stopAllTasks

### Changed
- update webpages for version v1.2.68

### Fixed
- update stopAllTasks to suspend RfidReaderTask instead of NfcTask

## [1.2.67] - 2025-02-20
### Added
- improve OTA upload handling and add SPIFFS update support

### Changed
- update webpages for version v1.2.67

## [1.2.66] - 2025-02-20
### Added
- enhance OTA upload to support SPIFFS updates

### Changed
- update webpages for version v1.2.66

## [1.2.65] - 2025-02-20
### Changed
- update webpages for version v1.2.65

## [1.2.64] - 2025-02-20
### Changed
- update webpages for version v1.2.64

### Fixed
- improve error handling in OTA upload process

## [1.2.63] - 2025-02-20
### Added
- update version to 1.2.63

### Changed
- update webpages for version v1.2.63

## [1.2.62] - 2025-02-20
### Added
- update version to 1.2.62

### Changed
- update webpages for version 1.2.62

## [1.2.61] - 2025-02-20
### Added
- update version to 1.2.61 and enhance OTA update error handling

### Changed
- update webpages for version 1.2.61

## [1.2.60] - 2025-02-20
### Added
- update version to 1.2.60 in platformio configuration

### Changed
- update webpages for version 1.2.60

## [1.2.59] - 2025-02-20
### Added
- update version to 1.2.59 and enhance OTA upload handling

### Changed
- update webpages for version 1.2.59

## [1.2.58] - 2025-02-20
### Added
- update version to 1.2.58 in HTML files and platformio configuration

## [1.2.57] - 2025-02-20
### Added
- update version to 1.2.57 in platformio configuration

### Fixed
- update spiffs offset and sizes in firmware and partitions configuration

## [1.2.56] - 2025-02-19
### Added
- update version to 1.2.56 and adjust firmware and partition settings

### Changed
- remove redundant comment from Gitea release workflow

## [1.2.55] - 2025-02-19
### Added
- update version to 1.2.55 and adjust Gitea release workflow to remove 'v' prefix from version

## [1.2.54] - 2025-02-19
### Added
- update version to 1.2.54 and add check for missing changelog in Gitea release workflow

## [1.2.53] - 2025-02-19
### Added
- update version to 1.2.53 and enhance Gitea release workflow to handle missing changelog

## [1.2.52] - 2025-02-19
### Added
- update version to 1.2.52 and improve Gitea release workflow output handling

## [1.2.51] - 2025-02-19
### Added
- update version to 1.2.51 and add debug output in Gitea release workflow

## [1.2.50] - 2025-02-19
### Added
- update version to 1.2.50 and remove obsolete build workflow

## [1.2.49] - 2025-02-19
### Added
- update version to 1.2.49 and modify changelog reading in Gitea release workflow

## [1.2.48] - 2025-02-19
### Added
- update version to 1.2.48 and modify changelog reading in release workflows

## [1.2.47] - 2025-02-19
### Added
- update version to 1.2.47 and modify changelog reading in GitHub release workflow

## [1.2.46] - 2025-02-19
### Added
- update Gitea release workflow to include changelog and increment version to 1.2.46

## [1.2.45] - 2025-02-19
### Added
- update Gitea release workflow to use dynamic upload URL and increment version to 1.2.45

## [1.2.44] - 2025-02-19
### Added
- update Gitea release workflow to include additional outputs and increment version to 1.2.44

## [1.2.43] - 2025-02-19
### Added
- update Gitea release workflow by removing unnecessary outputs and increment version to 1.2.43

## [1.2.42] - 2025-02-19
### Added
- update Gitea release workflow to include additional outputs and increment version to 1.2.42

## [1.2.41] - 2025-02-19
### Added
- update Gitea release workflow debug output and increment version to 1.2.41

## [1.2.40] - 2025-02-19
### Added
- add inputs for Gitea release workflow and increment version to 1.2.40

## [1.2.39] - 2025-02-19
### Added
- update Gitea release workflow to use Python virtual environment and increment version to 1.2.39

## [1.2.38] - 2025-02-19
### Added
- update Gitea release workflow and increment version to 1.2.38

## [1.2.37] - 2025-02-19
### Added
- update Gitea release workflow and increment version to 1.2.37

## [1.2.36] - 2025-02-19
### Added
- update Gitea release workflow and increment version to 1.2.36

## [1.2.35] - 2025-02-19
### Added
- update Gitea release workflow and version to 1.2.35

## [1.2.34] - 2025-02-19
### Added
- update version to 1.2.34 and enhance Gitea and GitHub release workflows

## [1.2.33] - 2025-02-19
### Added
- update version to 1.2.33 and refactor release workflows for Gitea and GitHub

## [1.2.32] - 2025-02-19
### Added
- update version to 1.2.32 and adjust workflow dependencies for GitHub and Gitea releases

## [1.2.31] - 2025-02-19
### Added
- update version to 1.2.31

## [1.2.30] - 2025-02-19
### Added
- update version to 1.2.30 and enhance release workflows for Gitea and GitHub with improved artifact handling and changelog integration

## [1.2.29] - 2025-02-19
### Added
- update version to 1.2.29 and enhance Gitea release workflow with improved error handling and debugging

## [1.2.28] - 2025-02-19
### Added
- add build and release workflows for Gitea and GitHub, increment version to 1.2.28

## [1.2.27] - 2025-02-19
### Added
- enhance CI workflows with provider detection and update version to 1.2.27

## [1.2.26] - 2025-02-19
### Added
- update release workflows for Gitea and GitHub, increment version to 1.2.26

## [1.2.25] - 2025-02-19
### Added
- update GitHub release workflows and increment version to 1.2.25

## [1.2.24] - 2025-02-19
### Added
- update GitHub release workflow and increment version to 1.2.24

## [1.2.23] - 2025-02-19
### Added
- update Gitea release workflow and increment version to 1.2.23

## [1.2.22] - 2025-02-19
### Added
- update Gitea runner configuration and increment version to 1.2.22

## [1.2.21] - 2025-02-19
### Added
- update Gitea release condition and increment version to 1.2.21

## [1.2.20] - 2025-02-19
### Added
- update release workflows for GitHub and Gitea, increment version to 1.2.20

## [1.2.19] - 2025-02-19
### Added
- add Gitea and GitHub release workflows for version 1.2.19

## [1.2.18] - 2025-02-19
### Added
- remove Gitea and GitHub release workflows and increment version to 1.2.18

## [1.2.17] - 2025-02-19
### Added
- update Gitea release workflow for version 1.2.17 and improve job structure

## [1.2.16] - 2025-02-19
### Added
- update Gitea release workflow and increment version to 1.2.16

## [1.2.15] - 2025-02-19
### Added
- update version to 1.2.15 and clean up Gitea release workflow

## [1.2.14] - 2025-02-19
### Added
- update version to 1.2.14 and refactor release workflows for improved GitHub and Gitea support

## [1.2.13] - 2025-02-19
### Added
- update version to 1.2.13 and enhance release workflow with Python setup and Gitea support

## [1.2.12] - 2025-02-19
### Added
- update version to 1.2.12 and refactor release workflows for improved provider detection and execution

## [1.2.11] - 2025-02-18
### Added
- update version to 1.2.11 and enhance GitHub and Gitea release workflows with input validation and improved error handling

## [1.2.10] - 2025-02-18
### Added
- enhance Gitea release workflow with API connection verification and URL validation; update version to 1.2.10

## [1.2.9] - 2025-02-18
### Added
- update version to 1.2.9 in platformio.ini
- refactor GitHub and Gitea release workflows for improved version handling and firmware uploads

## [1.2.8] - 2025-02-18
### Added
- update version to 1.2.8 in platformio.ini; refactor Gitea and GitHub release workflows
- update version to 1.2.7 in platformio.ini; adjust Gitea release workflow

## [1.2.6] - 2025-02-18
### Added
- update version to 1.2.6 in platformio.ini
- update version to 1.2.5; enhance Gitea release workflow and streamline release process

### Changed
- update changelog for version 1.2.5

## [1.2.5] - 2025-02-18
### Added
- update version to 1.2.5; enhance Gitea release workflow and streamline release process

## [1.2.4] - 2025-02-18
### Added
- update version to 1.2.4 in HTML files and platformio.ini
- add GitHub and Gitea release workflows; streamline firmware release process

## [1.2.3] - 2025-02-18
### Added
- update version to 1.2.3; modify HTML files to reflect new version; enhance firmware update process and UI improvements

## [1.2.2] - 2025-02-18
### Added
- update version to 1.2.2; change OTA upgrade link in HTML files; enhance OTA upload handling with progress updates and JSON responses
- implement OTA update functionality with web interface; update partition settings and build configuration
- remove unused OTA server setup and related includes; update platformio.ini dependencies
- adjust weight counter threshold and optimize delay in RFID scanning; include scale header in NFC module
- update version to v1.2.1 and change upgrade link to OTA in HTML files; modify updateSpoolTagId function to return boolean

## [1.2.0] - 2025-02-17
### Added
- implement OTA functionality and update build scripts; change upgrade link to OTA in HTML
- update version to v1.2.0 and modify build scripts in platformio.ini; remove unused includes in scale.cpp and website.cpp
- update version to v1.2.0 and add upgrade link in HTML files
- add esp_wifi.h and set maximum transmit power in WiFi initialization

### Changed
- update changelog for version 1.1.0
- clean up changelog and update script execution in platformio.ini
- update changelog for version 1.1.0

### Fixed
- update version number in header to v1.1.0
- correct version number in nav bar

## [1.1.0] - 2025-02-16
### Changed
- clean up changelog and update script execution in platformio.ini
- update changelog for version 1.1.0

### Fixed
- correct version number in nav bar

## [1.0.5] - 2025-02-16
### Added
- update version to 1.0.5 and enhance changelog update process with automatic git push
- update changelog script to categorize commits and handle new changelog creation
- improve changelog update script to handle absolute paths and create new changelog if missing

## [1.0.4] - 2025-02-16
### Added
- improve changelog update script to handle absolute paths and create new changelog if missing

## [1.0.3] - 2025-02-16
### Added
- 

### Changed
-

### Fixed
-

## [1.0.2] - 2025-02-16
### Added
- Feature 1
- Feature 2

### Changed
- Change 1
- Change 2

### Fixed
- Fix 1
- Fix 2

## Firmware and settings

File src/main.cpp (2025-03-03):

#include <Arduino.h>
#include <Wire.h>
#include <WiFi.h>

#include "wlan.h"
#include "config.h"
#include "website.h"
#include "api.h"
#include "display.h"
#include "bambu.h"
#include "nfc.h"
#include "scale.h"
#include "esp_task_wdt.h"
#include "commonFS.h"

bool mainTaskWasPaused = 0;
uint8_t scaleTareCounter = 0;

// ##### SETUP #####
void setup() {
  Serial.begin(115200);

  uint64_t chipid;

  chipid = ESP.getEfuseMac(); //The chip ID is essentially its MAC address(length: 6 bytes).
  Serial.printf("ESP32 Chip ID = %04X", (uint16_t)(chipid >> 32)); //print High 2 bytes
  Serial.printf("%08X\n", (uint32_t)chipid); //print Low 4bytes.

  // Initialize SPIFFS
  initializeFileSystem();

  // Start Display
  setupDisplay();

  // WiFiManager
  initWiFi();

  // Webserver
  setupWebserver(server);

  // Spoolman API
  // api.cpp
  initSpoolman();

  // Bambu MQTT
  setupMqtt();

  // NFC Reader
  startNfc();

  start_scale();

  // WDT initialisieren mit 10 Sekunden Timeout
  bool panic = true; // Wenn true, löst ein WDT-Timeout einen System-Panik aus
  esp_task_wdt_init(10, panic);

  // Aktuellen Task (loopTask) zum Watchdog hinzufügen
  esp_task_wdt_add(NULL);
}


/**
 * Safe interval check that handles millis() overflow
 * @param currentTime Current millis() value
 * @param lastTime Last recorded time
 * @param interval Desired interval in milliseconds
 * @return True if interval has elapsed
 */
bool intervalElapsed(unsigned long currentTime, unsigned long &lastTime, unsigned long interval) {
  if (currentTime - lastTime >= interval || currentTime < lastTime) {
    lastTime = currentTime;
    return true;
  }
  return false;
}

unsigned long lastWeightReadTime = 0;
const unsigned long weightReadInterval = 1000; // 1 second

unsigned long lastAutoSetBambuAmsTime = 0;
const unsigned long autoSetBambuAmsInterval = 1000; // 1 second
uint8_t autoAmsCounter = 0;

uint8_t weightSend = 0;
int16_t lastWeight = 0;

unsigned long lastWifiCheckTime = 0;
const unsigned long wifiCheckInterval = 60000; // Überprüfe alle 60 Sekunden (60000 ms)

// ##### PROGRAM START #####
void loop() {
  unsigned long currentMillis = millis();

  // Überprüfe regelmäßig die WLAN-Verbindung
  if (intervalElapsed(currentMillis, lastWifiCheckTime, wifiCheckInterval)) {
    checkWiFiConnection();
  }

  // Wenn Bambu auto set Spool aktiv
  if (autoSendToBambu && autoSetToBambuSpoolId > 0) {
    if (intervalElapsed(currentMillis, lastAutoSetBambuAmsTime, autoSetBambuAmsInterval)) 
    {
      if (hasReadRfidTag == 0)
      {
        lastAutoSetBambuAmsTime = currentMillis;
        oledShowMessage("Auto Set         " + String(autoSetBambuAmsCounter - autoAmsCounter) + "s");
        autoAmsCounter++;

        if (autoAmsCounter >= autoSetBambuAmsCounter) 
        {
          autoSetToBambuSpoolId = 0;
          autoAmsCounter = 0;
          oledShowWeight(weight);
        }
      }
      else
      {
        autoAmsCounter = 0;
      }
    }
  }

  // Wenn Waage nicht Kalibriert
  if (scaleCalibrated == 3) 
  {
    oledShowMessage("Scale not calibrated!");
    vTaskDelay(5000 / portTICK_PERIOD_MS);
    yield();
    esp_task_wdt_reset();
    
    return;
  } 

  // Ausgabe der Waage auf Display
  if(pauseMainTask == 0)
  {
    if (mainTaskWasPaused || (weight != lastWeight && hasReadRfidTag == 0 && (!autoSendToBambu || autoSetToBambuSpoolId == 0)))
    {
      (weight < 2) ? ((weight < -2) ? oledShowMessage("!! -0") : oledShowWeight(0)) : oledShowWeight(weight);
    }
    mainTaskWasPaused = false;
  }
  else
  {
    mainTaskWasPaused = true;
  }


  // Wenn Timer abgelaufen und nicht gerade ein RFID-Tag geschrieben wird
  if (currentMillis - lastWeightReadTime >= weightReadInterval && hasReadRfidTag < 3)
  {
    lastWeightReadTime = currentMillis;

    // Prüfen ob die Waage korrekt genullt ist
    if ((weight > 0 && weight < 5) || weight < 0)
    {
      if(scaleTareCounter < 5)
      {
        scaleTareCounter++;
      }
      else
      {
        scaleTareRequest = true;
        scaleTareCounter = 0;
      }
      
    }
    else
    {
      scaleTareCounter = 0;
    }

    // Prüfen ob das Gewicht gleich bleibt und dann senden
    if (weight == lastWeight && weight > 5)
    {
      weigthCouterToApi++;
    } 
    else 
    {
      weigthCouterToApi = 0;
      weightSend = 0;
    }
  }

  // reset weight counter after writing tag
  if (currentMillis - lastWeightReadTime >= weightReadInterval && hasReadRfidTag > 1)
  {
    weigthCouterToApi = 0;
  }
  
  lastWeight = weight;

  // Wenn ein Tag mit SM id erkannte wurde und der Waage Counter anspricht an SM Senden
  if (spoolId != "" && weigthCouterToApi > 3 && weightSend == 0 && hasReadRfidTag == 1) {
    oledShowIcon("loading");
    if (updateSpoolWeight(spoolId, weight)) 
    {
      oledShowIcon("success");
      vTaskDelay(2000 / portTICK_PERIOD_MS);
      weightSend = 1;
      autoSetToBambuSpoolId = spoolId.toInt();

      if (octoEnabled) 
      {
        updateSpoolOcto(autoSetToBambuSpoolId);
      }
    }
    else
    {
      oledShowIcon("failed");
      vTaskDelay(2000 / portTICK_PERIOD_MS);
    }
  }
  
  esp_task_wdt_reset();
}

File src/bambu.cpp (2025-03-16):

#include "bambu.h"
#include <ArduinoJson.h>
#include <PubSubClient.h>
#include <WiFiManager.h>
#include <SSLClient.h>
#include "bambu_cert.h"
#include "website.h"
#include "nfc.h"
#include "commonFS.h"
#include "esp_task_wdt.h"
#include "config.h"
#include "display.h"

WiFiClient espClient;
SSLClient sslClient(&espClient);
PubSubClient client(sslClient);

TaskHandle_t BambuMqttTask;

String report_topic = "";
//String request_topic = "";
const char* bambu_username = "bblp";
const char* bambu_ip = nullptr;
const char* bambu_accesscode = nullptr;
const char* bambu_serialnr = nullptr;

String g_bambu_ip = "";
String g_bambu_accesscode = "";
String g_bambu_serialnr = "";

bool bambu_connected = false;
bool autoSendToBambu = false;
int autoSetToBambuSpoolId = 0;

// Globale Variablen für AMS-Daten
int ams_count = 0;
String amsJsonData;  // Speichert das fertige JSON für WebSocket-Clients
AMSData ams_data[MAX_AMS];  // Definition des Arrays;

bool saveBambuCredentials(const String& ip, const String& serialnr, const String& accesscode, bool autoSend, const String& autoSendTime) {
    if (BambuMqttTask) {
        vTaskDelete(BambuMqttTask);
    }
    
    JsonDocument doc;
    doc["bambu_ip"] = ip;
    doc["bambu_accesscode"] = accesscode;
    doc["bambu_serialnr"] = serialnr;
    doc["autoSendToBambu"] = autoSend;
    doc["autoSendTime"] = (autoSendTime != "") ? autoSendTime.toInt() : autoSetBambuAmsCounter;

    if (!saveJsonValue("/bambu_credentials.json", doc)) {
        Serial.println("Fehler beim Speichern der Bambu-Credentials.");
        return false;
    }

    // Dynamische Speicherallokation für die globalen Pointer
    bambu_ip = ip.c_str();
    bambu_accesscode = accesscode.c_str();
    bambu_serialnr = serialnr.c_str();
    autoSendToBambu = autoSend;
    autoSetBambuAmsCounter = autoSendTime.toInt();

    vTaskDelay(100 / portTICK_PERIOD_MS);
    if (!setupMqtt()) return false;

    return true;
}

bool loadBambuCredentials() {
    JsonDocument doc;
    if (loadJsonValue("/bambu_credentials.json", doc) && doc["bambu_ip"].is<String>()) {
        // Temporäre Strings für die Werte
        String ip = doc["bambu_ip"].as<String>();
        String code = doc["bambu_accesscode"].as<String>();
        String serial = doc["bambu_serialnr"].as<String>();

        g_bambu_ip = ip;
        g_bambu_accesscode = code;
        g_bambu_serialnr = serial;

        if (doc["autoSendToBambu"].is<bool>()) autoSendToBambu = doc["autoSendToBambu"].as<bool>();
        if (doc["autoSendTime"].is<int>()) autoSetBambuAmsCounter = doc["autoSendTime"].as<int>();

        ip.trim();
        code.trim();
        serial.trim();

        // Dynamische Speicherallokation für die globalen Pointer
        bambu_ip = g_bambu_ip.c_str();
        bambu_accesscode = g_bambu_accesscode.c_str();
        bambu_serialnr = g_bambu_serialnr.c_str();

        report_topic = "device/" + String(bambu_serialnr) + "/report";
        //request_topic = "device/" + String(bambu_serialnr) + "/request";
        return true;
    }
    Serial.println("Keine gültigen Bambu-Credentials gefunden.");
    return false;
}

struct FilamentResult {
    String key;
    String type;
};

FilamentResult findFilamentIdx(String brand, String type) {
    // JSON-Dokument für die Filament-Daten erstellen
    JsonDocument doc;
    
    // Laden der own_filaments.json
    String ownFilament = "";
    if (!loadJsonValue("/own_filaments.json", doc)) 
    {
        Serial.println("Fehler beim Laden der eigenen Filament-Daten");
    }
    else
    {
        // Durchsuche direkt nach dem Type als Schlüssel
        if (doc[type].is<String>()) {
            ownFilament = doc[type].as<String>();
        }
        doc.clear();
    }
    doc.clear();

    // Laden der bambu_filaments.json
    if (!loadJsonValue("/bambu_filaments.json", doc)) 
    {
        Serial.println("Fehler beim Laden der Filament-Daten");
        return {"GFL99", "PLA"}; // Fallback auf Generic PLA
    }

    // Wenn eigener Typ
    if (ownFilament != "")
    {
        if (doc[ownFilament].is<String>()) 
        {
            return {ownFilament, doc[ownFilament].as<String>()};
        }
    }

    // 1. Erst versuchen wir die exakte Brand + Type Kombination zu finden
    String searchKey;
    if (brand == "Bambu" || brand == "Bambulab") {
        searchKey = "Bambu " + type;
    } else if (brand == "PolyLite") {
        searchKey = "PolyLite " + type;
    } else if (brand == "eSUN") {
        searchKey = "eSUN " + type;
    } else if (brand == "Overture") {
        searchKey = "Overture " + type;
    } else if (brand == "PolyTerra") {
        searchKey = "PolyTerra " + type;
    }

    // Durchsuche alle Einträge nach der Brand + Type Kombination
    for (JsonPair kv : doc.as<JsonObject>()) {
        if (kv.value().as<String>() == searchKey) {
            return {kv.key().c_str(), kv.value().as<String>()};
        }
    }

    // 2. Wenn nicht gefunden, zerlege den type String in Wörter und suche nach jedem Wort
    // Sammle alle vorhandenen Filamenttypen aus der JSON
    std::vector<String> knownTypes;
    for (JsonPair kv : doc.as<JsonObject>()) {
        String value = kv.value().as<String>();
        // Extrahiere den Typ ohne Markennamen
        if (value.indexOf(" ") != -1) {
            value = value.substring(value.indexOf(" ") + 1);
        }
        if (!value.isEmpty()) {
            knownTypes.push_back(value);
        }
    }

    // Zerlege den Input-Type in Wörter
    String typeStr = type;
    typeStr.trim();
    
    // Durchsuche für jedes bekannte Filament, ob es im Input vorkommt
    for (const String& knownType : knownTypes) {
        if (typeStr.indexOf(knownType) != -1) {
            // Suche nach diesem Typ in der Original-JSON
            for (JsonPair kv : doc.as<JsonObject>()) {
                String value = kv.value().as<String>();
                if (value.indexOf(knownType) != -1) {
                    return {kv.key().c_str(), knownType};
                }
            }
        }
    }

    // 3. Wenn immer noch nichts gefunden, gebe GFL99 zurück (Generic PLA)
    return {"GFL99", "PLA"};
}

bool sendMqttMessage(const String& payload) {
    Serial.println("Sending MQTT message");
    Serial.println(payload);
    if (client.publish(report_topic.c_str(), payload.c_str())) 
    {
        return true;
    }
    
    return false;
}
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

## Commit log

2025-02-13 add 3D print files for Bottom, Housing, and Table
    [Bottom.3mf, Housing.3mf, Table.3mf]
2025-02-13 add PN532 pin configuration details to README
2025-02-13 refactor CSS styles for reboot button and adjust input width in bambu settings
2025-02-13 update "Buy Me A Coffee" button size in README for better visibility
2025-02-13 add script to combine firmware and SPIFFS binaries, and remove unused display files
    [partitions.csv]
2025-02-13 add PlatformIO configuration file for ESP32 development with custom build targets
2025-02-14 fix: update Bambu spool settings and connection handling logic
    [bambu.cpp]
2025-02-14 fix: update MQTT connection logic to handle failures correctly and not try to connect random
    [bambu.cpp]
2025-02-14 fix: add additional Bambu spool settings and update API response structure
    [api.cpp]
2025-02-14 fix: update MQTT connection logic to ensure proper task creation and connection handling
    [bambu.cpp]
2025-02-14 fix: correct label for filament index in tray properties
2025-02-14 fix: enhance Bambu spool handling by adding tray info index and improving logging
    [bambu.cpp]
2025-02-14 fix: improve reconnect logic by replacing delay with yield and vTaskDelay
    [bambu.cpp]
2025-02-15 fix: add calibration index to tray properties and update related logic
    [bambu.cpp]
2025-02-15 refactor: remove combined binary creation script and related configurations
    [partitions.csv]
2025-02-15 fix: update calibration index check in displayAmsData function
2025-02-15 feat: add calibration index handling to tray data and update related API and UI components
2025-02-16 feat: update GitHub Actions workflow for firmware release and add partition configuration
    [partitions.csv]
2025-02-16 fix: update partition settings and version in platformio.ini, and enhance release workflow
    [partitions.csv]
2025-02-16 feat: add esp_wifi.h and set maximum transmit power in WiFi initialization
2025-02-18 feat: implement OTA update functionality with web interface; update partition settings and build configuration
    [partitions.csv]
2025-02-18 feat: update version to 1.2.3; modify HTML files to reflect new version; enhance firmware update process and UI improvements
    [partitions.csv]
2025-02-19 feat: update version to 1.2.56 and adjust firmware and partition settings
    [partitions.csv]
2025-02-19 fix: update spiffs offset and sizes in firmware and partitions configuration
    [partitions.csv]
2025-02-20 feat: update version to 1.2.61 and enhance OTA update error handling
    [ota.cpp]
2025-02-20 fix: improve error handling in OTA upload process
    [ota.cpp]
2025-02-20 fix: update stopAllTasks to suspend RfidReaderTask instead of NfcTask
    [ota.cpp]
2025-02-20 fix: add logging to stopAllTasks for better debugging
    [ota.cpp]
2025-02-20 fix: update version number to v1.2.65 in HTML files and platformio.ini; add script to create full binary
    [ota.cpp, wlan.cpp]
2025-02-20 refactor: simplify OTA update handling by removing unnecessary variables and improving error reporting
    [ota.cpp]
2025-02-20 refactor: update Gitea and GitHub release workflows to improve binary preparation and verification fix: correct version number in HTML files and platformio.ini to v1.2.76 enhance: streamline OTA upda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
    [ota.cpp]
2025-02-20 refactor: update Gitea and GitHub release workflows to include new firmware and SPIFFS binaries; fix version display in HTML files to v1.2.78
    [ota.cpp]
2025-02-20 refactor: update Gitea and GitHub release workflows to use esp32dev_ota for building and uploading firmware and SPIFFS binaries
2025-02-20 fix: update SPIFFS offset and size in release workflows and partitions.csv
    [partitions.csv]
2025-02-20 fix: update firmware build process and remove unused OTA environment
    [ota.cpp]
2025-02-20 fix: improve OTA update handling and logging for better error reporting
    [ota.cpp]
2025-02-20 refactor: enhance OTA update process with SPIFFS support and improved error handling
    [ota.cpp]
2025-02-21 refactor: update SPIFFS initialization and partition sizes; enhance WiFi setup
    [partitions.csv]
2025-02-21 refactor: migrate calibration value storage from EEPROM to NVS
2025-02-22 partition: update app sizes and offsets in partitions.csv
    [partitions.csv]
2025-02-22 partition: update spiffs offset in partition files
    [partitions.csv]
2025-02-22 partition: update spiffs offset and app sizes in partition files
    [partitions.csv]
2025-02-22 partition: update SPIFFS binary creation and offsets in workflow files
    [partitions.csv]
2025-02-22 partition: update SPIFFS binary header and offsets in workflow files
    [partitions.csv]
2025-02-22 workflow: update ESP32-WROOM image header for SPIFFS binary creation
2025-02-22 workflow: update SPIFFS binary creation with minimal ESP32 image header
2025-02-22 fix: update SPIFFS binary header and enhance WebSocket error handling
    [website.cpp]
2025-02-22 fix: update SPIFFS binary creation and enhance NFC buffer size
    [main.cpp, nfc.cpp, website.cpp]
2025-02-22 fix: remove redundant buffer size setting in NFC initialization
    [nfc.cpp]
2025-02-22 docs: update header title to 'Filament Management Tool' and improve update response messages
2025-02-22 workflow: update SPIFFS binary magic byte and revert version to 1.3.51
    [website.cpp]
2025-02-22 docs: update header title and improve SPIFFS update error handling
    [website.cpp]
2025-02-22 docs: update header title to 'Filament Management Tool' in multiple HTML files
2025-02-23 feat: implement scale calibration checks and update start_scale function to return calibration status
2025-02-23 docs: update README files with HSPI default PINs and add ESP32 pin diagram
2025-02-23 feat: improve UI for Spoolman and Bambu Lab printer credentials, enhancing layout and styling
2025-02-23 fix: update weight display logic to handle negative and specific weight cases
    [main.cpp]
2025-02-23 fix: adjust weight display logic to handle cases for weight less than 2
    [main.cpp]
2025-02-23 fix: update comment to clarify NVS reading process
    [scale.cpp]
2025-02-24 fix: configure CPU frequency settings in setup function only for testing
    [main.cpp]
2025-02-24 fix: remove unnecessary CPU frequency configuration from setup function
    [main.cpp]
2025-02-24 docs: update README to reflect PN532 I2C configuration and remove SPI pin details
2025-02-24 docs: add wiring diagrams to README for PN532 I2C setup
2025-02-24 refactor: simplify filament names in JSON configuration
2025-02-24 fix: enhance weight display logic for negative values
    [main.cpp]
2025-02-24 fix: remove debug output from splitTextIntoLines and update weight display logic in scanRfidTask
    [display.cpp, nfc.cpp]
2025-02-24 fix: correct payload type check in NFC write event handling
    [website.cpp]
2025-02-25 feat: add own_filaments.json and integrate custom filament loading in bambu.cpp
2025-02-25 fix: update auto set logic to check RFID tag before setting Bambu spool
    [main.cpp]
2025-02-25 feat: add espRestart function and replace delay with vTaskDelay for OTA update process
    [ota.cpp]
2025-02-25 feat: erweitere Bambu-Credentials mit AutoSend-Wartezeit und aktualisiere die Benutzeroberfläche
2025-02-25 feat: erweitere Bambu-Credentials um AutoSend-Zeit und aktualisiere die Benutzeroberfläche
2025-02-25 fix: aktualisiere Bedingung für den Fortschritt der OTA-Update-Nachricht
    [ota.cpp]
2025-02-25 fix: aktualisiere Bedingungen für die AMS-Datenaktualisierung und entferne unnötige Aufrufe
    [bambu.cpp, main.cpp]
2025-02-25 feat: entferne die sendAmsData-Funktion aus der API-Schnittstelle
2025-02-25 feat: füge Unterstützung für Spoolman-Einstellungen hinzu und aktualisiere die Benutzeroberfläche
2025-02-25 docs: füge Link zum Wiki für detaillierte Informationen über die Nutzung hinzu
2025-02-27 feat: aktualisiere OLED-Anzeige mit Versionsnummer und verbessere Textausrichtung
2025-02-27 refactor: entferne ungenutzte Bibliotheken und Debug-Ausgaben aus main.cpp
2025-02-27 feat: verbessere WLAN-Konfiguration und füge mDNS-Unterstützung hinzu
2025-02-27 fix: optimiere Verzögerungen und Stackgrößen in NFC-Task-Funktionen
    [nfc.cpp]
2025-02-27 fix: behebe doppelte http.end() Aufrufe in checkSpoolmanExtraFields
    [api.cpp]
2025-02-28 Improves NFC Tag handling
    Fixes memory underflow when reading tags. Reads tags with their actual data size and uses actual size instead of constnat value for tag size when writing a tag.
    [nfc.cpp]
2025-03-01 remove unused version and protocol fields from JSON output; add error message for insufficient memory
    [nfc.cpp]
2025-03-01 update NFC tag references to include NTAG213 and clarify storage capacity
2025-03-01 refactor: adjust stack size and improve scale calibration logic
2025-03-01 refactor: remove redundant scale calibration checks and enhance task management
2025-03-02 feat: add new 3D print file for Filaman scale
    [FilaMan-Waage.step]
2025-03-03 Reworks the scale calibration handling
    Fixes some issues in the scale handling. Prevents a wdg reset after
    after scale calibration. Also makes sure that after calibration all
    tasks are started again that have been suspsended before.
    [main.cpp, scale.cpp]
2025-03-03 added pictures showing heat insert location
2025-03-03 added pictures for heat insert location
2025-03-04 added .stp files of modifications
    [Base_usermod_spitzbirne32.stp, FilaMan-Scale_usermod_spitzbirne32.stp, Housing_usermod_spitzbirne32.stp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]
2025-03-06 removed CAD, as they were all duplicates
    [Base_usermod_spitzbirne32.stp, Housing_usermod_spitzbirne32.stp, ScaleTop_usermod_spitzbirne32.stp]
2025-03-06 added new .step, now with correct individual parts
    [Base_usermod_spitzbirne32.stp, Housing_usermod_spitzbirne32.stp, ScaleTop_usermod_spitzbirne32.stp]
2025-03-06 improved housing to show display better
    [FilaMan-Scale_usermod_spitzbirne32.stp]
2025-03-11 Update README.de.md
    Einige Kleinigkeiten die mir aufgefallen sind.
    - einheitlich Bambu Lab
    - generell Namensgebung korrigiert
    - die meisten Auflistungen haben ein . am Ende, eigentlich könnte man die weglassen, aber ich habe die, die keine hatten angepasst
    - Installation Google Chrome oder Microsoft Edge hinzugefügt
2025-03-12 Update README.de.md
    Removed OpenSpool
